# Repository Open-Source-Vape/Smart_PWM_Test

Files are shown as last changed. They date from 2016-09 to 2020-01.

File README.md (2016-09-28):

/*
 * Components used:
 * https://www.adafruit.com/products/931
 * https://www.sparkfun.com/products/9028
 * https://www.sparkfun.com/products/8374
 * https://www.sparkfun.com/products/13760
 * https://www.sparkfun.com/products/97
 * http://www.infineon.com/cms/en/product/power/power-mosfet/20v-300v-n-channel-power-mosfet/20v-30v-n-channel-power-mosfet/IRLS3813/productType.html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
 * https://www.radioshack.com/products/radioshack-220-ohm-1-4w-5-carbon-film-resistor-pk-5
 * place 220 ohm resistor between MCU pin 7 and gate on mosfet 
 */

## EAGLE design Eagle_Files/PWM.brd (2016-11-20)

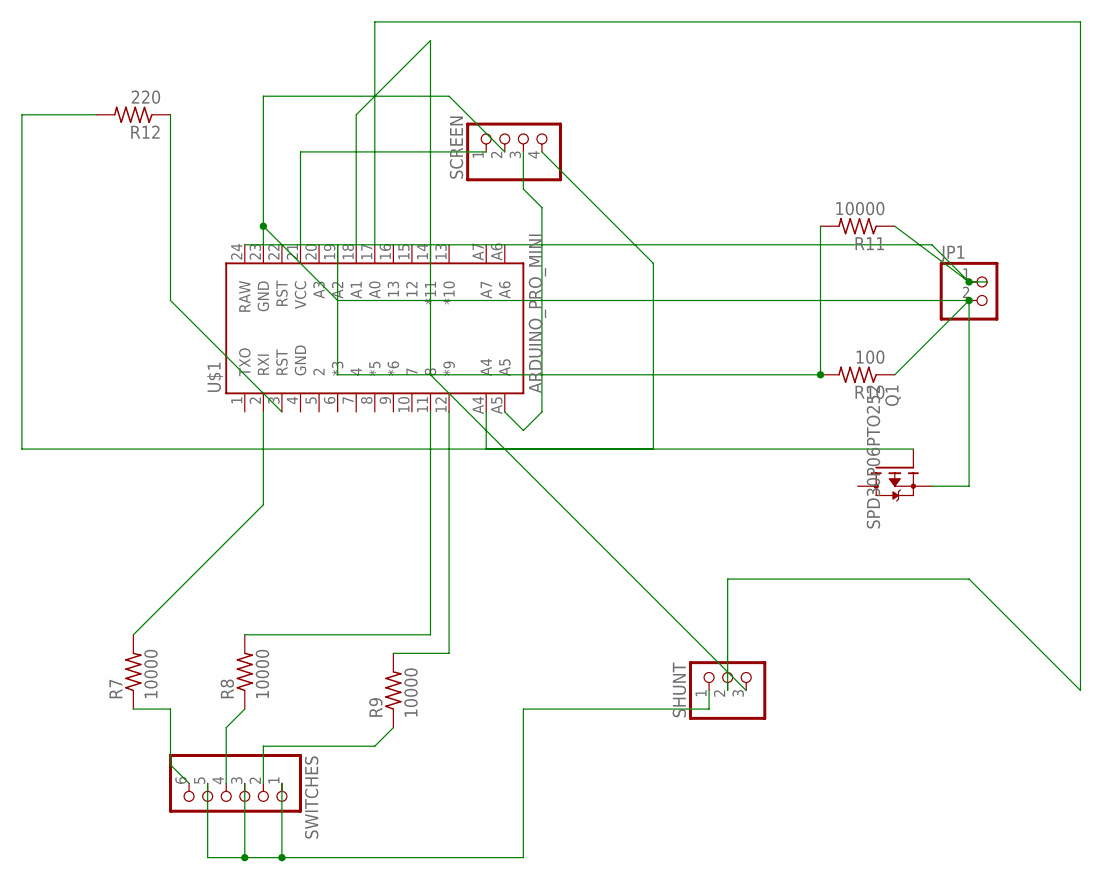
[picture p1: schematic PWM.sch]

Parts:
JP1: PINHD-1X2; 1X02
Q1: SPD30P06PTO252; TO252
R7, R8, R9, R11: 10000; 0204/7
R10: 100; 0204/7
R12: 220; 0204/7
SCREEN: PINHD-1X4; 1X04
SHUNT: PINHD-1X3; 1X03
SWITCHES: PINHD-1X6; 1X06
U$1: ARDUINO_PRO_MINI

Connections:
2: R7.1, R7.2, SWITCHES.6, U$1.2 (RXI)
3: R12.1, U$1.3 (RST)
11: R8.1, SWITCHES.4
12: R9.1, SWITCHES.2
19: R10.2, R11.2, U$1.19 (A2)
A0: SHUNT.2, U$1.17 (A0)
A1: SHUNT.3, U$1.18 (A1)
A4: SCREEN.4, U$1.A4
A5: SCREEN.3, U$1.A5
FET: Q1.1 (G), R12.2
GND: JP1.2, Q1.2 (S), R10.1, SCREEN.2, SHUNT.1, SWITCHES.1, SWITCHES.3, SWITCHES.5, U$1.23 (GND)
unnamed: R9.2, U$1.12 (*9)
unnamed: R8.2, U$1.11 (8)
RAW: JP1.1, R11.1, U$1.24 (RAW)
VCC: SCREEN.1, U$1.21 (VCC)

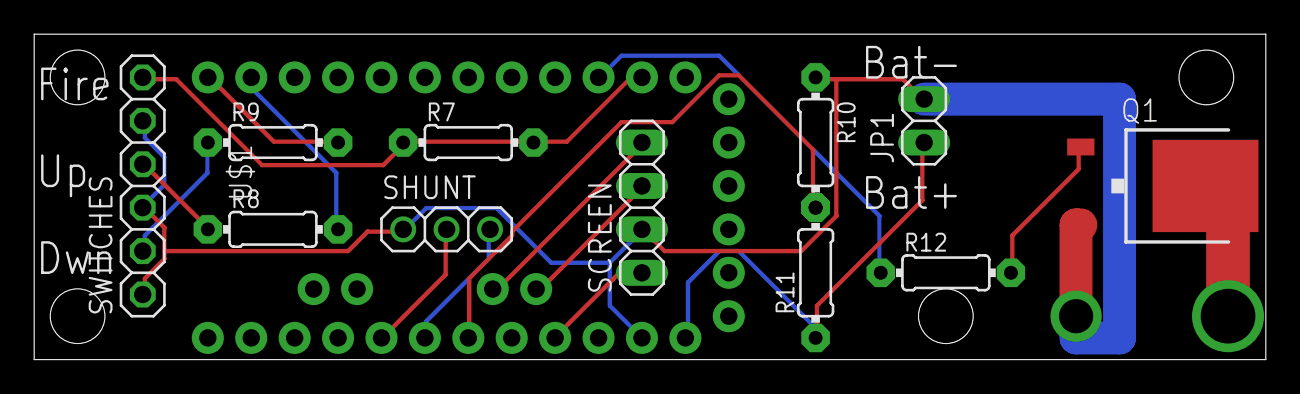
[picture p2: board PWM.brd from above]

Board: 2 copper layers, 72.1 x 19.0 mm, 12 parts (0 on the bottom side), 15 nets.

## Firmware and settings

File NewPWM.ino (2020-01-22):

/*
  Components used:
  https://www.adafruit.com/products/931
  https://www.sparkfun.com/products/9028
  https://www.sparkfun.com/products/8374
  https://www.sparkfun.com/products/13760
  https://www.sparkfun.com/products/97
  http://www.infineon.com/cms/en/product/power/power-mosfet/20v-300v-n-channel-power-mosfet/20v-30v-n-channel-power-mosfet/IRLS3813/productType.html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
  https://www.radioshack.com/products/radioshack-220-ohm-1-4w-5-carbon-film-resistor-pk-5
  place 220 ohm resistor between MCU pin 7 and gate on mosfet
  todo:
  fixup userland editable PWM frequency and set limits for oscillation 
  fixup locking mechanism
  fixup display prettyness
  write my own graphics lib with better fonts and smoothing
  
*/

#include <PWM.h>
#include <Wire.h>
#include <Adafruit_SSD1306.h>
#include <Adafruit_GFX.h>
#include <gfxfont.h>
#include <avr/sleep.h>
#include <avr/interrupt.h>
#include <EEPROM.h>

#define OLED_RESET 4
Adafruit_SSD1306 display(OLED_RESET);
#define LOGO16_GLCD_HEIGHT 16
#define LOGO16_GLCD_WIDTH  16

#define uppin 12
#define downpin 11
const uint8_t firepin = 2;
const uint8_t BUTTON_INT = digitalPinToInterrupt(firepin);
#define battpin A2
#define mosfetpin 3

int wattaddress = 0;
int battaddress = 5;
int freq_address = 10;

volatile int32_t frequency = 200;
volatile int32_t last_freq;
int switchstate;
bool switchstateup;
bool switchstatedown;
bool powerlock = 0;
int lock;
int last_watt;
int curr_watt;
int menu_freq;
int menu_res_offset = 0;
int menu_curr = 1;
int sleeping;


int pulsestate;
int pulseran;
int outputpwm = 0;
int outputvalue = 0;
int output = 0;

float VFinal;
float IFinal;
float RFinal;
float WUser = 1;
float WUser_Temp = 0;
float IProj;
int VRaw;
int IRaw;
int voltageValue = 0;
float vout = 0.0;
float vin = 0.0;
float vRMS;
//these values are for the resistors used in voltage divider
float R1 = 100000.0;
float R2 = 10000.0;
int battery;
enum {twoS, threeS, fourS};

byte batt_type;
byte batt_kind;
byte batt_last;

long millis_held;
long millis_wait;
long prev_secs_held;
long secs_held;
long secondslock;
byte previous = LOW;
byte previousup = LOW;
byte previousdown = LOW;
unsigned long firsttime;
unsigned long locktime;
int counter = 0;
int last_state = 0;
int setup_ran = 0;

void setup () {
  InitTimersSafe();
  bool success = SetPinFrequencySafe(mosfetpin, frequency);
  pinMode(mosfetpin, OUTPUT);
  if (success) {
    pinMode(13, OUTPUT);
    digitalWrite(13, HIGH);
  }
  display.begin(SSD1306_SWITCHCAPVCC, 0x3C);
  display.clearDisplay();
  display.setTextSize(2);
  display.setTextColor(WHITE);
  display.setCursor(0, 0);
  display.println("Cloud 9");
  display.display();
  delay(100);
  pinMode(uppin, INPUT_PULLUP);
  pinMode(downpin, INPUT);
  pinMode(firepin, INPUT);
  pinMode(battpin, INPUT);
  pinMode(A0, INPUT);
  pinMode(A1, INPUT);
  pinMode(A2, INPUT);
  attachInterrupt(BUTTON_INT, interrupt, CHANGE);
  EEPROM.get(wattaddress, WUser);
  EEPROM.get(freq_address, frequency);
  readbattery();
  setup_ran = 1;

}

void loop () {
  vRMS = sqrt(WUser * RFinal);
  output = (vRMS / VFinal * vRMS / VFinal ) * 255;
  output = constrain(output, 0, 255);
  //readbattery raw with voltage divider to get unloaded status
  readbattery();
  drawbattery();

  switchstate = digitalRead(firepin);
  switchstateup = digitalRead(uppin);
  switchstatedown = digitalRead(downpin);
  firecheck();
  updowncheck();
  project();
  drawscreen();

}
void firecheck() {
  if (switchstate == HIGH && previous == LOW && (millis() - firsttime) > 200) {
    firsttime = millis();

  }
  if (switchstate != last_state && (secondslock > 15) ) {
    locktime = millis();
    counter = 0;
  }
  if (switchstate == HIGH) {

    millis_held = (millis() - firsttime);
    secs_held = millis_held / 100;
    millis_wait = (millis() - locktime);
    secondslock = millis_wait / 100;

    if (secs_held >= 3) {
      //do fire stuff hehe
      pulsecheck();
      if (pulsestate == 1  && lock == 0)
      {
        curr_watt = WUser;
        pwmWrite(mosfetpin, output);


      }

    }
  }
  delay(5);
  if (secs_held <= 5 && switchstate != last_state) {


    if (secondslock <= 5) {
      counter++;
      if (counter >= 4 && lock == 0) {
        counter = 0;
        lock = 1;
      }

      if (counter >= 4 && lock == 1) {
        lock = 0;
        counter = 0;
      }
    }
  }

  delay(10);

  previous = switchstate;
  last_state = switchstate;


  if (switchstate == LOW) {
    last_watt = WUser;
    if (curr_watt != last_watt) {
      EEPROM.put(wattaddress, WUser);
    }
    //do not firing stuff
    if (pulsestate)
      pwmWrite(mosfetpin, 0);
    pulseran = 0;
    millis_held = 0;
    secs_held = 0;
  }
}
void drawscreen() {
  if (lock == 0 && menu_res_offset == 0) {
    display.clearDisplay();
    display.setTextSize(1);
    display.setTextColor(WHITE);
    display.setCursor(0, 0);
    display.drawRect(0, 0, 30, 9, WHITE);
    drawbattery();
    display.setCursor(32, 0);
    display.print("%");
    display.setCursor(40, 0);
    display.print(battery);
    display.setCursor(0, 12);
    display.print("Amp= ");
    display.setCursor(23, 12);
    display.print(IProj, 1);
    display.setCursor(0, 23);
    display.print("Vout=");
    display.setCursor(32, 23);
    display.print(vRMS);
    display.setCursor(65, 0);
    display.setTextSize(2);
    display.print("W=");
    display.setCursor(88, 0);
    display.print(WUser, 0);
    display.setTextSize(1);
    display.setCursor(65, 15);
    display.print("R=");
    display.setCursor(77, 15);
    display.print(menu_res_offset);
    display.setCursor(65, 23);
    display.print("Duty=");
    display.setCursor(95, 23);
    display.print(output);
    //setContrast(display, 255);
    display.display();
  }
  if (lock == 1 && sleeping == 0) {
    
    display.clearDisplay();
    display.display();
    display.setTextSize(1);
    display.setTextColor(WHITE);
    display.setCursor(0, 0);
    display.println("LOCKED");
    display.display();
    noInterrupts();
    delay(1000);
    interrupts();
    sleepnow();
    sleeping = 1;
  }
  if (lock == 1 && sleeping == 1) {
    display.clearDisplay();
    display.display();
    sleepnow();
    sleeping = 1;
  }
  if (menu_res_offset == 1 && lock == 0 ) {
    display.clearDisplay();
    display.setTextSize(1);
    display.setCursor(0, 0);
    display.print("Freq:");
    display.setCursor(35, 0);
    display.setTextSize(2);
    display.print(frequency);
    display.display();
  }
}
void pulsecheck() {

  if (pulseran == 0 && lock == 0) {
    digitalWrite(mosfetpin, HIGH);
    delay(35);
    VRaw = analogRead(A0);
    IRaw = analogRead(A1);
    VFinal = VRaw / 12.99;
    IFinal = IRaw / 7.4;
    RFinal = VFinal / IFinal - 0.03; //the .26 may not be needed i think it is the resistance of the board itself though or the overall circuit
    if (RFinal >= 0.23) {
      pulsestate = 1;
      pulseran = 1;
    }
    //need to fix the logic behind a low resistance coil / short / no coil
    if (RFinal >= 0.1 && RFinal <= .23) {
      //low resistance message
      pulsestate = 0;
      pulseran = 0 ;
      //RFinal = 0;
    }
    else if (RFinal <= 0) {
      pulsestate = 0;
      pulseran = 0;
    }
    else if (RFinal == NAN) {
      pulsestate = 0;
      pulseran = 0;
      RFinal = 0;
    }
    delay(15);
    digitalWrite(mosfetpin, LOW);
  }
  if (pulsestate == 0  && lock == 0) {
    display.clearDisplay();
    display.setTextSize(1);
    display.setTextColor(WHITE);
    display.setCursor(0, 0);
    display.print("No Coil");
    display.setCursor(0, 10);
    display.print(pulsestate);
    display.display();
    delay(100);
    pulseran = 0;
    if (IProj == NAN) {
      IProj = 0;
    }
    if (IProj == INFINITY) {
      IProj = 0;
    }
    if (vRMS == NAN) {
      vRMS = 0;
    }
    if (RFinal == NAN) {
      RFinal == 0;
    }
  }
}
void updowncheck() {
  if (switchstateup == HIGH & switchstatedown == HIGH) {
    menu_res_offset++;
    delay(50);
    if (menu_res_offset <= 0) {
      menu_res_offset = 0;
    }
    if (menu_res_offset >= 2) {
      menu_res_offset = 0;
    }
  }

  if (menu_res_offset == 1 && lock == 0) {
    last_freq = frequency;
    if (switchstateup == HIGH && switchstatedown == LOW) {
      frequency = frequency + 25;
    }
    delay(50);
    if (switchstatedown == HIGH && switchstateup == LOW) {
      frequency = frequency -25;
    }
    delay(50);
    if (frequency > 25000) {
      frequency = 25000;
    }
    if (frequency < 100) {
      frequency = 100;

    }
  if (last_freq != frequency) {
    EEPROM.put(freq_address, frequency);
  }
  }
  
  if (powerlock == 0 && menu_res_offset == 0 && lock == 0) {
    if (switchstateup == HIGH && previousup == LOW && (millis() - firsttime) > 200) {
      firsttime = millis();
    }

    if (switchstateup == HIGH) {
      millis_held = (millis() - firsttime);
      secs_held = millis_held / 100;
      if (secs_held >= 4) {
        WUser = WUser + 2;
      }
      if (secs_held <= 3) {
        WUser ++;
        delay(100);
      }
    }


    previousup = switchstateup;

    if (switchstatedown == HIGH && previousdown == LOW && (millis() - firsttime) > 200) {
      firsttime = millis();
    }

    if (switchstatedown == HIGH) {
      millis_held = (millis() - firsttime);
      secs_held = millis_held / 100;
      if (secs_held >= 4) {
        WUser = WUser - 2;
      }
      if (secs_held <= 3) {
        WUser --;
        delay(100);
      }
    }
    previousdown = switchstatedown;

    if (switchstatedown == HIGH)
    {
      WUser--;
      delay(25);
    }
    if (WUser <= 1) WUser = 1;
    {
      // DIsplay min wattage error
    }
  }

}

void project() {
  IProj = sqrt(WUser / RFinal);
}

void drawbattery() {
  if (batt_kind = 1) {
    battery = map (vin, 0, 8.4, 0, 100);
  }
  if (batt_kind = 2) {
    battery = map (vin, 0, 12.6, 0, 100);
  }
  if (batt_kind = 3) {
    battery = map (vin, 0, 16.8, 0, 100);
  }
  switch (battery) {
    case 100:
      display.fillRect(0, 0, 30, 9, WHITE);
      break;
    case 99:
      display.fillRect(0, 0, 30, 9, WHITE);
      break;
    case 98:
      display.fillRect(0, 0, 30, 9, WHITE);
      break;
    case 97:
      display.fillRect(0, 0, 30, 9, WHITE);
      break;
    case 96:
      display.fillRect(0, 0, 30, 9, WHITE);
      break;
    case 95:
      display.fillRect(0, 0, 30, 9, WHITE);
      break;
    case 94:
      display.fillRect(0, 0, 30, 9, WHITE);
      break;
    case 93:
      display.fillRect(0, 0, 30, 9, WHITE);
      break;
    case 92:
      display.fillRect(0, 0, 30, 9, WHITE);
      break;
    case 91:
      display.fillRect(0, 0, 30, 9, WHITE);
      break;
    case 90:
      display.fillRect(0, 0, 30, 9, WHITE);
      break;
    case 89:
      display.fillRect(0, 0, 30, 9, WHITE);
      break;
    case 88:
      display.fillRect(0, 0, 30, 9, WHITE);
      break;
    case 87:
      display.fillRect(0, 0, 30, 9, WHITE);
      break;
    case 86:
      display.fillRect(0, 0, 30, 9, WHITE);
      break;
    case 85:
      display.fillRect(0, 0, 30, 9, WHITE);
      break;
    case 84:
      display.fillRect(0, 0, 30, 9, WHITE);
      break;
    case 83:
      display.fillRect(0, 0, 30, 9, WHITE);
      break;
    case 82:
      display.fillRect(0, 0, 30, 9, WHITE);
      break;
    case 81:
      display.fillRect(0, 0, 30, 9, WHITE);
      break;
    case 80:
      display.fillRect(0, 0, 30, 9, WHITE);
      break;
    case 79:
      display.fillRect(0, 0, 20, 9, WHITE);
      break;
    case 77:
      display.fillRect(0, 0, 20, 9, WHITE);
      break;
    case 76:
      display.fillRect(0, 0, 20, 9, WHITE);
      break;
    case 75:
      display.fillRect(0, 0, 20, 9, WHITE);
      break;
    case 74:
      display.fillRect(0, 0, 20, 9, WHITE);
      break;
    case 73:
      display.fillRect(0, 0, 20, 9, WHITE);
      break;
    case 72:
      display.fillRect(0, 0, 20, 9, WHITE);
      break;
    case 71:
      display.fillRect(0, 0, 20, 9, WHITE);
      break;
    case 70:
      display.fillRect(0, 0, 20, 9, WHITE);
      break;
    case 69:
      display.fillRect(0, 0, 20, 9, WHITE);
      break;
    case 68:
      display.fillRect(0, 0, 20, 9, WHITE);
      break;
    case 67:
      display.fillRect(0, 0, 20, 9, WHITE);
      break;
    case 66:
      display.fillRect(0, 0, 20, 9, WHITE);
      break;
    case 65:
      display.fillRect(0, 0, 20, 9, WHITE);
      break;
    case 64:
      display.fillRect(0, 0, 20, 9, WHITE);
      break;
    case 63:
      display.fillRect(0, 0, 20, 9, WHITE);
      break;
    case 62:
      display.fillRect(0, 0, 20, 9, WHITE);
      break;
    case 61:
      display.fillRect(0, 0, 20, 9, WHITE);
      break;
    case 60:
      display.fillRect(0, 0, 20, 9, WHITE);
      break;
    case 59:
      display.fillRect(0, 0, 20, 9, WHITE);
      break;
    case 58:
      display.fillRect(0, 0, 20, 9, WHITE);
      break;
    case 57:
      display.fillRect(0, 0, 20, 9, WHITE);
      break;
    case 56:
      display.fillRect(0, 0, 20, 9, WHITE);
      break;
    case 55:
      display.fillRect(0, 0, 20, 9, WHITE);
      break;
    case 54:
      display.fillRect(0, 0, 20, 9, WHITE);
      break;
    case 53:
      display.fillRect(0, 0, 20, 9, WHITE);
      break;
    case 52:
      display.fillRect(0, 0, 20, 9, WHITE);
      break;
    case 51:
      display.fillRect(0, 0, 20, 9, WHITE);
      break;
    case 50:
      display.fillRect(0, 0, 20, 9, WHITE);
      break;
    case 49:
      display.fillRect(0, 0, 20, 9, WHITE);
      break;
    case 48:
      display.fillRect(0, 0, 20, 9, WHITE);
      break;
    case 47:
      display.fillRect(0, 0, 20, 9, WHITE);
      break;
    case 46:
      display.fillRect(0, 0, 20, 9, WHITE);
      break;
    case 45:
      display.fillRect(0, 0, 20, 9, WHITE);
      break;
    case 44:
      display.fillRect(0, 0, 10, 9, WHITE);
      break;
    case 43:
      display.fillRect(0, 0, 10, 9, WHITE);
      break;
    case 42:
      display.fillRect(0, 0, 10, 9, WHITE);
      break;
    case 41:
      display.fillRect(0, 0, 10, 9, WHITE);
      break;
    case 40:
      display.fillRect(0, 0, 10, 9, WHITE);
      break;
    case 39:
      display.fillRect(0, 0, 10, 9, WHITE);
      break;
    case 38:
      display.fillRect(0, 0, 10, 9, WHITE);
      break;
    case 37:
      display.fillRect(0, 0, 10, 9, WHITE);
      break;
    case 36:
      display.fillRect(0, 0, 10, 9, WHITE);
      break;
    case 35:
      display.fillRect(0, 0, 10, 9, WHITE);
      break;
    case 34:
      display.fillRect(0, 0, 10, 9, WHITE);
      break;
    case 33:
      display.fillRect(0, 0, 10, 9, WHITE);
      break;
    case 32:
      display.fillRect(0, 0, 10, 9, WHITE);
      break;
    case 31:
      display.fillRect(0, 0, 10, 9, WHITE);
      break;
    case 30:
      display.fillRect(0, 0, 10, 9, WHITE);
      break;
    case 29:
      display.fillRect(0, 0, 0, 9, WHITE);
      break;
    case 28:
      display.fillRect(0, 0, 0, 9, WHITE);
      break;
    case 27:
      display.fillRect(0, 0, 0, 9, WHITE);
      break;
    case 26:
      display.fillRect(0, 0, 0, 9, WHITE);
      break;
    case 25:
      display.fillRect(0, 0, 0, 9, WHITE);
      break;
    case 24:
      display.fillRect(0, 0, 0, 9, WHITE);
      break;
    case 23:
      display.fillRect(0, 0, 0, 9, WHITE);
      break;
    case 22:
      display.fillRect(0, 0, 0, 9, WHITE);
      break;
    case 21:
      display.fillRect(0, 0, 0, 9, WHITE);
      break;
    case 20:
      display.fillRect(0, 0, 0, 9, WHITE);
      break;
    case 19:
      display.fillRect(0, 0, 0, 9, WHITE);
      break;
    case 18:
      display.fillRect(0, 0, 0, 9, WHITE);
      break;
    case 17:
      display.fillRect(0, 0, 0, 9, WHITE);
      break;
    case 16:
      display.fillRect(0, 0, 0, 9, WHITE);
      break;
    case 15:
      display.fillRect(0, 0, 0, 9, WHITE);
      break;
    case 14:
      display.fillRect(0, 0, 0, 9, WHITE);
      break;
    case 13:
      display.fillRect(0, 0, 0, 9, WHITE);
      break;
    case 12:
      display.fillRect(0, 0, 0, 9, WHITE);
      break;
    case 11:
      display.fillRect(0, 0, 0, 9, WHITE);
      break;
    case 10:
      display.fillRect(0, 0, 0, 9, WHITE);
      break;
  }

}
void readbattery() {
  voltageValue = analogRead(battpin);
  vout = (voltageValue * 5.26) / 1024.0;
  vin = vout / (R2 / (R1 + R2));
  if (setup_ran == 0) {
    if (vin < 0.09) {
      vin = 0.0;
    }
    if (vin >= 6.8 & vin <= 8.8) {
      batt_type = twoS;
    }
    if (vin >= 10.5 & vin <= 13.2) {
      batt_type = threeS;
    }
    if (vin >= 14 & vin <= 17.6) {
      batt_type = fourS;
    }
    switch (batt_type) {
      case twoS:
        constrain_2s();
        break;
      case threeS:
        constrain_3s();
        break;
      case fourS:
        constrain_4s();
        break;
      default:
        constrain_2s();
        break;
    }
    EEPROM.get(battaddress, batt_kind);
    if (batt_kind != batt_last) {
      EEPROM.put(battaddress, batt_kind);
    }
  }
}
void constrain_2s() {
  if (WUser > 250)
  { //display max wattage eror
    display.clearDisplay();
    display.setTextSize(1);
    display.setTextColor(WHITE);
    display.setCursor(0, 0);
    display.println("MAX WATTAGE");
    display.display();
    delay(100);
    WUser = 250;
    batt_kind = 1;
  }
}

void constrain_3s() {
  if (WUser > 375)
  { //display max wattage eror
    display.clearDisplay();
    display.setTextSize(1);
    display.setTextColor(WHITE);
    display.setCursor(0, 0);
    display.println("MAX WATTAGE");
    display.display();
    delay(100);
    WUser = 375;
    batt_kind = 2;
  }
}

void constrain_4s() {
  if (WUser > 500)
  { //display max wattage eror
    display.clearDisplay();
    display.setTextSize(1);
    display.setTextColor(WHITE);
    display.setCursor(0, 0);
    display.println("MAX WATTAGE");
    display.display();
    delay(100);
    WUser = 500;
    batt_kind = 3;
  }
}

void interrupt()
{
  sleep_disable();
  detachInterrupt(0);
  sleeping = 0;

}

void sleepnow() {
  set_sleep_mode (SLEEP_MODE_IDLE);
  sleep_enable();
  attachInterrupt(BUTTON_INT, interrupt, HIGH);
  sleep_mode();

}

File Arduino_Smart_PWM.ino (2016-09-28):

#include <PWM.h>
#include <Wire.h>
#include <SPI.h>
#include <Adafruit_SSD1306.h>
#include <Adafruit_GFX.h>
#include <gfxfont.h>

#define OLED_RESET 4
Adafruit_SSD1306 display(OLED_RESET);
#define LOGO16_GLCD_HEIGHT 16
#define LOGO16_GLCD_WIDTH  16

int battpin = A2;
int firepin = 7;
int mosfetpin = 3;
int uppin = 12;
int downpin = 11;


int32_t frequency = 120;
bool switchstate;
bool switchstateup;
bool switchstatedown;
int pulsestate;
int pulseran;
int outputpwm = 0;
int outputvalue = 0;
int outputbutton = 0;

float VFinal;
float IFinal;
float RFinal;
float WFinal;
byte WUser = 0;
int VRaw;
int IRaw;
int voltageValue = 0;
float vout = 0.0;
float vin = 0.0;
float R1 = 100000.0; 
float R2 = 10000.0; 

void setup () {
  InitTimersSafe();
  bool success = SetPinFrequencySafe(mosfetpin, frequency);
  if (success) {
    pinMode(13, OUTPUT);
    digitalWrite(13, HIGH);
  }
  display.begin(SSD1306_SWITCHCAPVCC, 0x3C);
  display.clearDisplay();
  pinMode(uppin, INPUT);
  pinMode(downpin, INPUT);
  pinMode(firepin, INPUT);
  pinMode(battpin, INPUT);
}

void loop () {
  //only use these for analog pot
  outputbutton = map(WUser, 0, 100, 0, 255);
  //clean up this for VV/VW later
  voltageValue=analogRead(battpin);
  vout=(voltageValue*5.26)/1024.0;
  vin = vout/ (R2/(R1+R2));
  
  switchstate = digitalRead(firepin);
  switchstateup = digitalRead(uppin);
  switchstatedown = digitalRead(downpin);

  if (switchstate == HIGH) {
    //do fire stuff
    if (pulseran == 0) {
      digitalWrite(mosfetpin, HIGH);
      delay(20);
      VRaw = analogRead(A0);
      IRaw = analogRead(A1);
      // these numbers are not valid ... yet...
      //1s input
      //VFinal = VRaw / 61.06;
      //IFinal = IRaw / 23.37165;
      //2s or greater ==
      VFinal = VRaw / 42.03;
      IFinal = IRaw / 16.99;
      
      RFinal = VFinal / IFinal;
      WFinal = VFinal * IFinal;
      
      digitalWrite(mosfetpin, LOW);

      if (RFinal > 0.1) {
        pulsestate = 1;
        pulseran = 1;
      }
      else if (RFinal <= 0) {
        pulsestate = 0;
        pulseran = 0;
      }
      else if (RFinal == NAN) {
        pulsestate = 0;
        pulseran = 0;
        RFinal = 0;
      }
    }
    if (pulsestate == 0) {
      display.clearDisplay();
      display.setTextSize(1);
      display.setTextColor(WHITE);
      display.setCursor(0, 0);
      display.print("No Coil");
      display.setCursor(0, 10);
      display.print(pulsestate);
      display.display();
      delay(100);
      pulseran = 0;
    }
    if (pulsestate == 1)
    {
      pwmWrite(mosfetpin, outputbutton);
    }
  }

  
  
  delay(10);

  
  if (switchstate == LOW) {
    //do not firing stuff
    if (pulsestate)
    pwmWrite(mosfetpin,0);
    pulseran = 0;
  }
  updowncheck();
  
  display.clearDisplay();
  display.setTextSize(1);
  display.setTextColor(WHITE);
  display.setCursor(0, 0);
  display.print("Vout=");
  display.setCursor(30, 0);
  display.print(VFinal);
  display.setCursor(0, 9);
  display.print("Amps=");
  display.setCursor(30, 9);
  display.print(IFinal);
  display.setCursor(0, 18);
  display.print("Duty=");
  display.setCursor(30, 18);
  display.print(WUser, 1);
  display.setCursor(0,27);
  display.print(vin);
  display.setCursor(70, 0);
  display.print("Fire =");
  display.setCursor(105, 0);
  display.print(switchstate);
  display.setCursor(70, 9);
  display.print(RFinal, 2);
  display.setCursor(70, 18);
  display.print(outputbutton);
  display.setCursor(70, 27);
  display.print(VRaw);
  display.setCursor(100, 18);
  display.print(pulsestate);
  display.setCursor(100, 27);
  display.print(pulseran);
  display.display();


}


void updowncheck() {
  if (switchstateup == LOW)
  {
    WUser++;
    delay(25);
  }
  if (switchstatedown == LOW)
  {
    WUser--;
    delay(25);
  }
  if (WUser >= 100) WUser = 100;
  { //display max wattage eror

  }
  if (WUser <= 1) WUser = 1;
  {
    // DIsplay min wattage error
  }
}

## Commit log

2016-09-11 initial commit of pwm code with screen printout of information
2016-09-11 Add code for 90a INA-169 breaktout to read current on fire
2016-09-11 add actual output for pwm pin
2016-09-11 add more information about current reader
2016-09-11 add quick math for resistance
2016-09-11 Update a println to a print char for VFinal and insert print for Rfinal
2016-09-11 rename high voltage to normal voltage operation
2016-09-11 rename power saving mode to a better name
2016-09-11 move quick check of voltage/current/resistance/wattage to occur only during firing
2016-09-11 disable eeprom writing of misc current calc bits
2016-09-11 Make check during pulse more realistic resistance value to look for
2016-09-11 turn off the pulse signal to ccheck resistance
2016-09-11 add 2 microsecond tick before continuing to check the resistance of the pulse
2016-09-11 hard code battery mode until sensing code is in place
2016-09-15 Trying to get LCD working layout is confusing but it prints information that is relative
2016-09-19 small overhaul.... replace analog write with pwm library and get PWM at 100k hz as to not be audible when switching.. (not sure of efficiency dont own a scope)
    [Arduino_Smart_PWM.ino]
2016-09-19 drop delay timer down for coil check a hair it seems to not need to fire very long at all to check if there is a coil with a 2s or greater supplying power
2016-09-19 add updown logic impliment wattage logic (not really active for now it just prints information doesnt use it. Change screen states to show live output vs user selected while firing and other stuff i 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
2016-09-28 Change Vout to Current Unloaded battery status
2016-09-28 add shitty battery thing
2016-09-29 man i suck at fritzing
    [test.fzz]
2016-09-30 add switch case array for battery charge level states
2016-09-30 finish battery array
2016-10-01 switch back because not using button lib
    [test.fzz]
2016-10-01 remove button header
2016-10-02 improve resistance check logic and change wattage levels to a more realistic output for a 2s setup
2016-10-02 fixup some debug stuff i was doing
    [NewPWM.ino]
2016-10-02 add longpress logic for down button
2016-10-16 been a while since internet no idea what i broke since last commit
    [NewPWM.ino]
2016-10-25 Change interrupts and add eeprom read/write of wattage
2016-10-25 fixup eeprom logic so it doesnt rape boards
    [NewPWM.ino]
2016-11-10 add max wattage error
    [NewPWM.ino]
2016-11-11 fixup battery checking logic
    [NewPWM.ino]
2016-11-17 add some eeprom storage for battery check on boot
2016-11-20 start staging menu for user to edit the frequency the PWM oscillates at
    [NewPWM.ino]
2016-11-20 add logic check to avoid user setting to high of freq or too low
    [NewPWM.ino]
2016-11-20 fixup menu logic a tad more
    [NewPWM.ino]
2016-11-20 fix max/min logic on frequency menu
    [NewPWM.ino]
2016-11-20 add prelim eagle files for backpack PCB
    [PWM.brd, PWM.sch]
2020-01-22 include the PWM library so folks can compile this

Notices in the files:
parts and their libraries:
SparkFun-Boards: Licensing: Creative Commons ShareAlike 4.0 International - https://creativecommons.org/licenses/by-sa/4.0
